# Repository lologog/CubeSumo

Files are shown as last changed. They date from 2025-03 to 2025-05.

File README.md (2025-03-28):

# CubeSumo - 🚧 Work in Progress
Minisumo robot built for sumo battles, equipped with multiple sensors for reliable navigation and opponent detection.

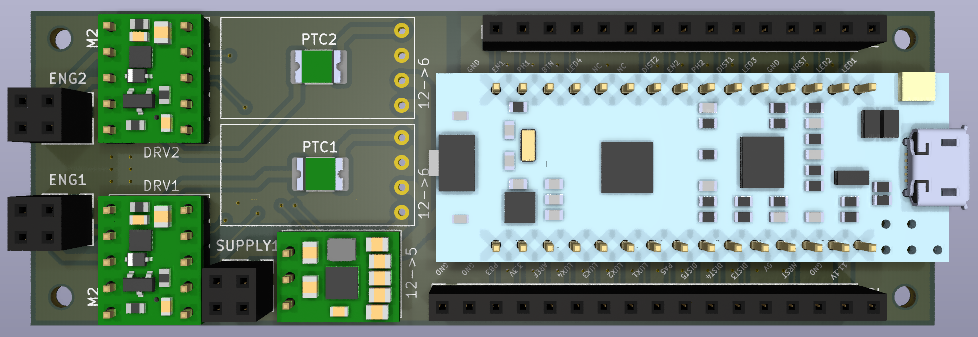
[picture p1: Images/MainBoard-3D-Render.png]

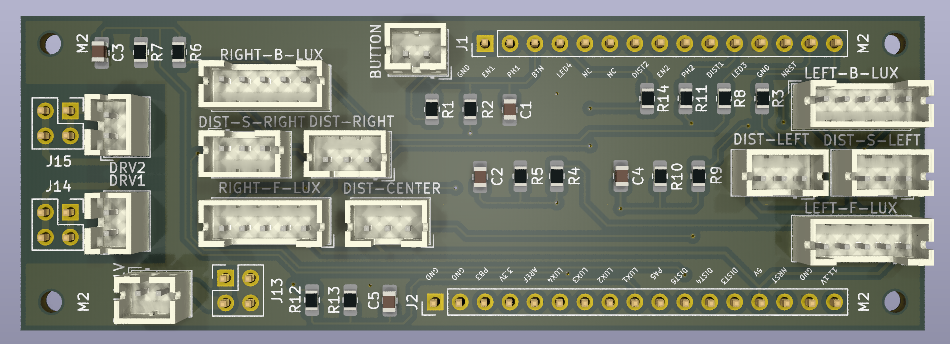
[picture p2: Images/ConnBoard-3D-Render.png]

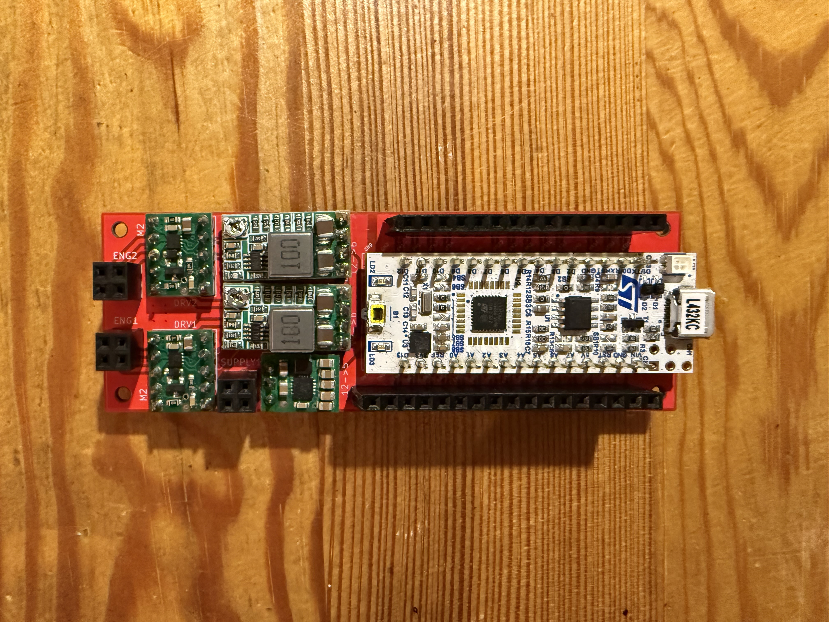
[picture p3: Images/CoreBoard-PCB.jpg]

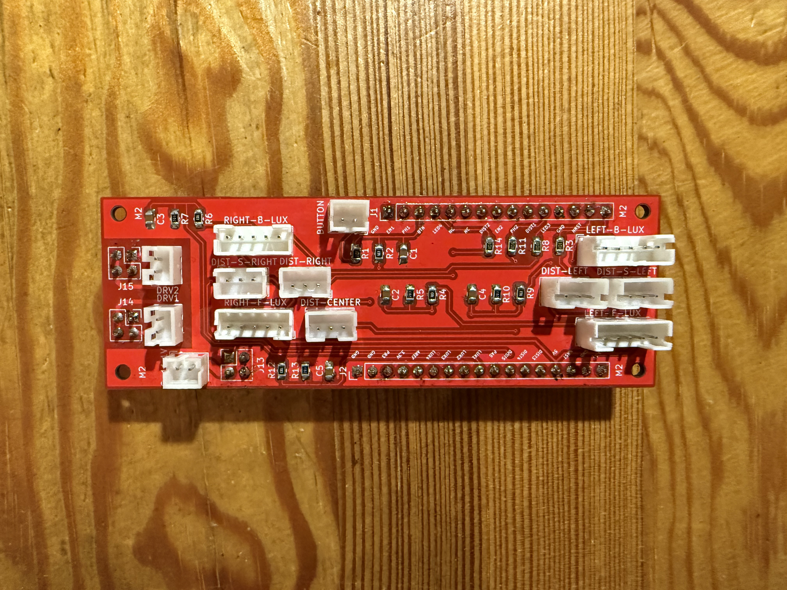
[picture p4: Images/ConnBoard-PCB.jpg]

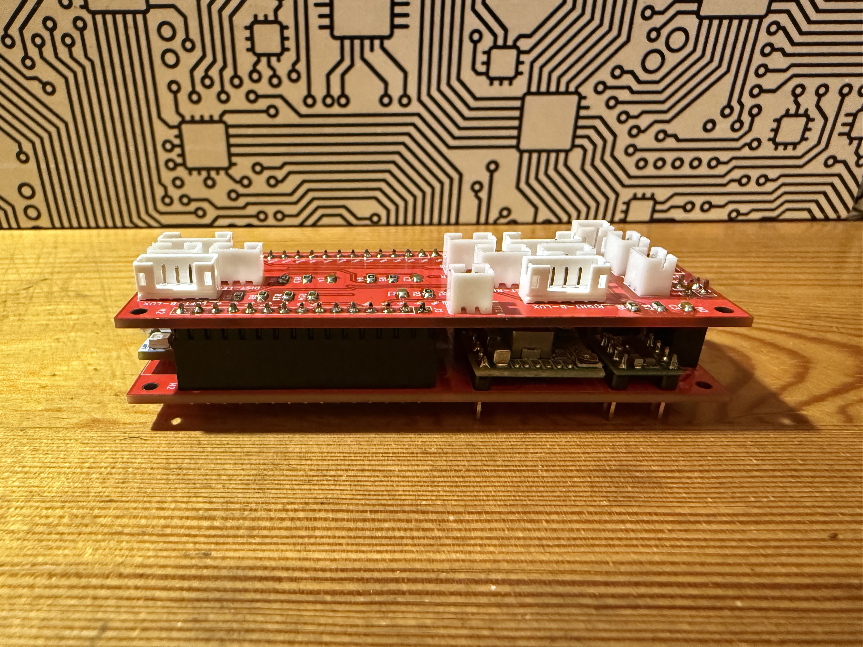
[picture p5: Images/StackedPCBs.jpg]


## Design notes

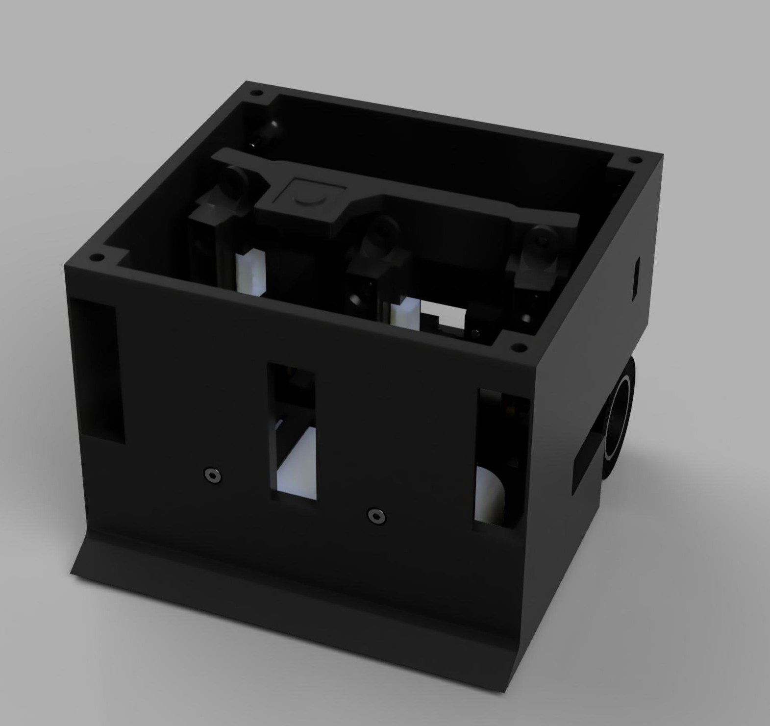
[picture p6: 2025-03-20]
Images/Zoeniowy_dziala_smaller.jpg

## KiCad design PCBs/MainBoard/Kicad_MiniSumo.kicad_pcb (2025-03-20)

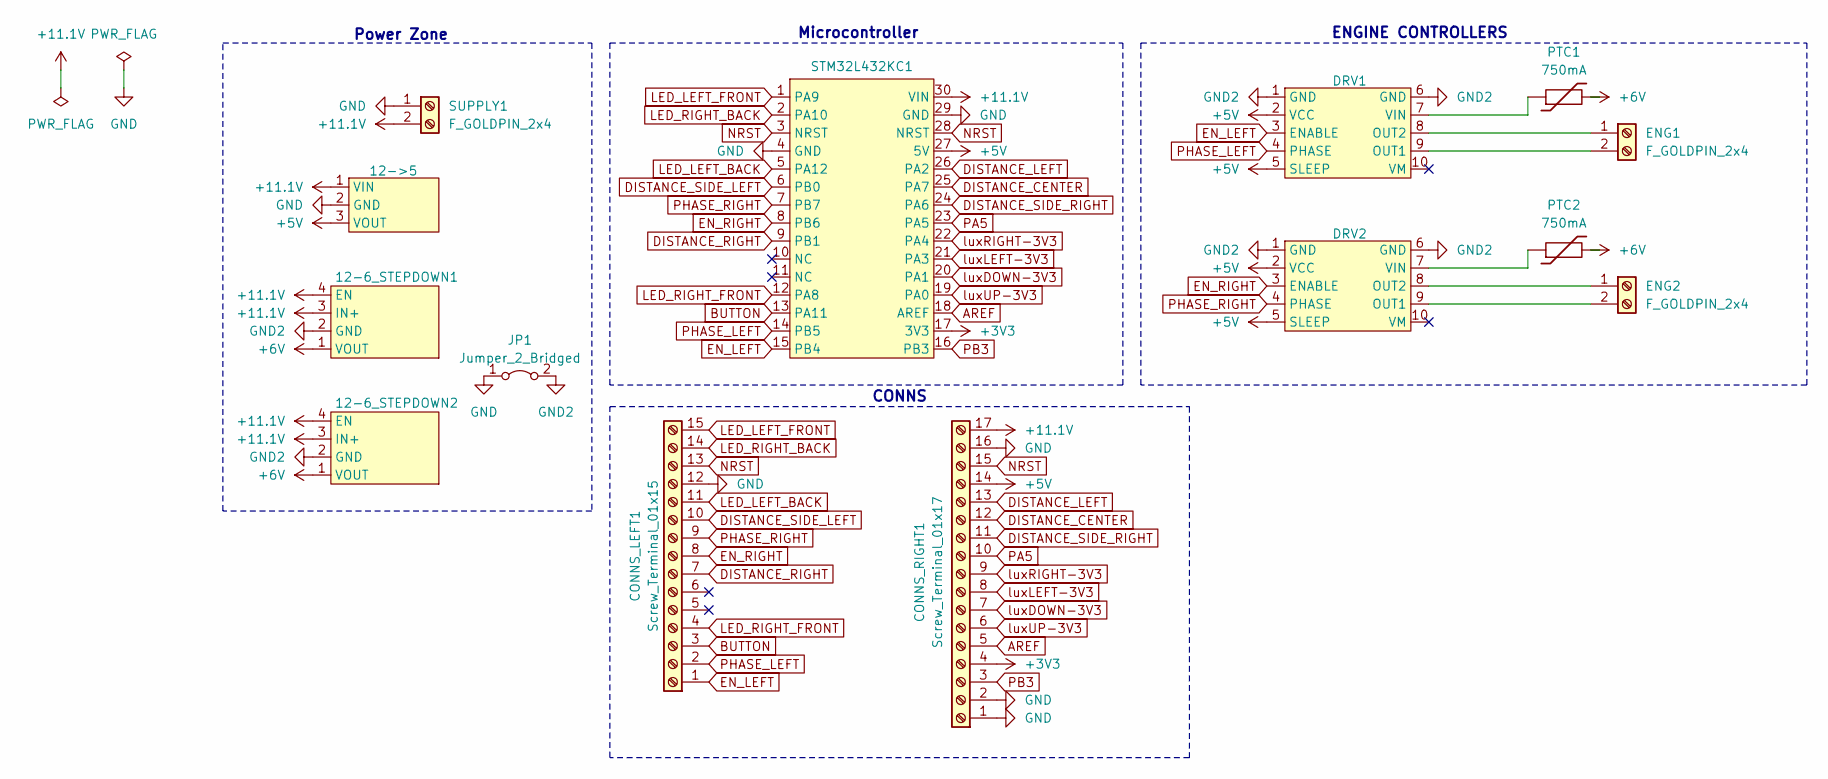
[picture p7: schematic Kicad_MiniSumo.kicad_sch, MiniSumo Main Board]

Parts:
12-6_STEPDOWN1, 12-6_STEPDOWN2: DC-DC Step-Down 0.8-17V 3A
12->5: S7V7F5
CONNS_LEFT1: Screw_Terminal_01x15; PinSocket_1x15_P2.54mm_Vertical
CONNS_RIGHT1: Screw_Terminal_01x17; PinSocket_1x17_P2.54mm_Vertical
DRV1, DRV2: DRV8838
ENG1, ENG2: F_GOLDPIN_2x4; PinSocket_2x02_P2.54mm_Vertical
JP1: Jumper_2_Bridged; SolderJumper-2_P1.3mm_Bridged2Bar_Pad1.0x1.5mm
PTC1, PTC2: 750mA; Fuse_1812_4532Metric_Pad1.30x3.40mm_HandSolder
STM32L432KC1: MODULE_NUCLEO-L432KC
SUPPLY1: F_GOLDPIN_2x4; PinSocket_2x02_P2.54mm_Vertical

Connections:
+3V3: CONNS_RIGHT1.4, STM32L432KC1.17 (3V3)
+5V: 12->5.3 (VOUT), CONNS_RIGHT1.14, DRV1.2 (VCC), DRV1.5 (SLEEP), DRV2.2 (VCC), DRV2.5 (SLEEP), STM32L432KC1.27 (5V)
+6V: 12-6_STEPDOWN1.1 (VOUT), 12-6_STEPDOWN2.1 (VOUT), PTC1.2, PTC2.2
+11.1V: 12-6_STEPDOWN1.3 (IN+), 12-6_STEPDOWN1.4 (EN), 12-6_STEPDOWN2.3 (IN+), 12-6_STEPDOWN2.4 (EN), 12->5.1 (VIN), CONNS_RIGHT1.17, STM32L432KC1.30 (VIN), SUPPLY1.2
AREF: CONNS_RIGHT1.5, STM32L432KC1.18 (AREF)
BUTTON: CONNS_LEFT1.3, STM32L432KC1.13 (PA11); also elsewhere on the board
DISTANCE_CENTER: CONNS_RIGHT1.12, STM32L432KC1.25 (PA7)
DISTANCE_LEFT: CONNS_RIGHT1.13, STM32L432KC1.26 (PA2)
DISTANCE_RIGHT: CONNS_LEFT1.7, STM32L432KC1.9 (PB1); also elsewhere on the board
DISTANCE_SIDE_LEFT: CONNS_LEFT1.10, STM32L432KC1.6 (PB0); also elsewhere on the board
DISTANCE_SIDE_RIGHT: CONNS_RIGHT1.11, STM32L432KC1.24 (PA6)
EN_LEFT: CONNS_LEFT1.1, DRV1.3 (ENABLE), STM32L432KC1.15 (PB4); also elsewhere on the board
EN_RIGHT: CONNS_LEFT1.8, DRV2.3 (ENABLE), STM32L432KC1.8 (PB6); also elsewhere on the board
GND: 12->5.2 (GND), CONNS_LEFT1.12, CONNS_RIGHT1.1, CONNS_RIGHT1.2, CONNS_RIGHT1.16, JP1.1 (A), STM32L432KC1.4 (GND), STM32L432KC1.29 (GND), SUPPLY1.1; also elsewhere on the board
GND2: 12-6_STEPDOWN1.2 (GND), 12-6_STEPDOWN2.2 (GND), DRV1.1 (GND), DRV1.6 (GND), DRV2.1 (GND), DRV2.6 (GND), JP1.2 (B)
LED_LEFT_BACK: CONNS_LEFT1.11, STM32L432KC1.5 (PA12); also elsewhere on the board
LED_LEFT_FRONT: CONNS_LEFT1.15, STM32L432KC1.1 (PA9); also elsewhere on the board
LED_RIGHT_BACK: CONNS_LEFT1.14, STM32L432KC1.2 (PA10); also elsewhere on the board
LED_RIGHT_FRONT: CONNS_LEFT1.4, STM32L432KC1.12 (PA8); also elsewhere on the board
NRST: CONNS_LEFT1.13, CONNS_RIGHT1.15, STM32L432KC1.3 (NRST), STM32L432KC1.28 (NRST); also elsewhere on the board
unnamed: DRV1.9 (OUT1), ENG1.2
unnamed: DRV1.8 (OUT2), ENG1.1
unnamed: DRV1.7 (VIN), PTC1.1
unnamed: DRV2.9 (OUT1), ENG2.2
unnamed: DRV2.8 (OUT2), ENG2.1
unnamed: DRV2.7 (VIN), PTC2.1
PA5: CONNS_RIGHT1.10, STM32L432KC1.23 (PA5)
PB3: CONNS_RIGHT1.3, STM32L432KC1.16 (PB3)
PHASE_LEFT: CONNS_LEFT1.2, DRV1.4 (PHASE), STM32L432KC1.14 (PB5); also elsewhere on the board
PHASE_RIGHT: CONNS_LEFT1.9, DRV2.4 (PHASE), STM32L432KC1.7 (PB7); also elsewhere on the board
luxDOWN-3V3: CONNS_RIGHT1.7, STM32L432KC1.20 (PA1)
luxLEFT-3V3: CONNS_RIGHT1.8, STM32L432KC1.21 (PA3)
luxRIGHT-3V3: CONNS_RIGHT1.9, STM32L432KC1.22 (PA4)
luxUP-3V3: CONNS_RIGHT1.6, STM32L432KC1.19 (PA0)

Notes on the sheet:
CONNS
Microcontroller
ENGINE CONTROLLERS
Power Zone

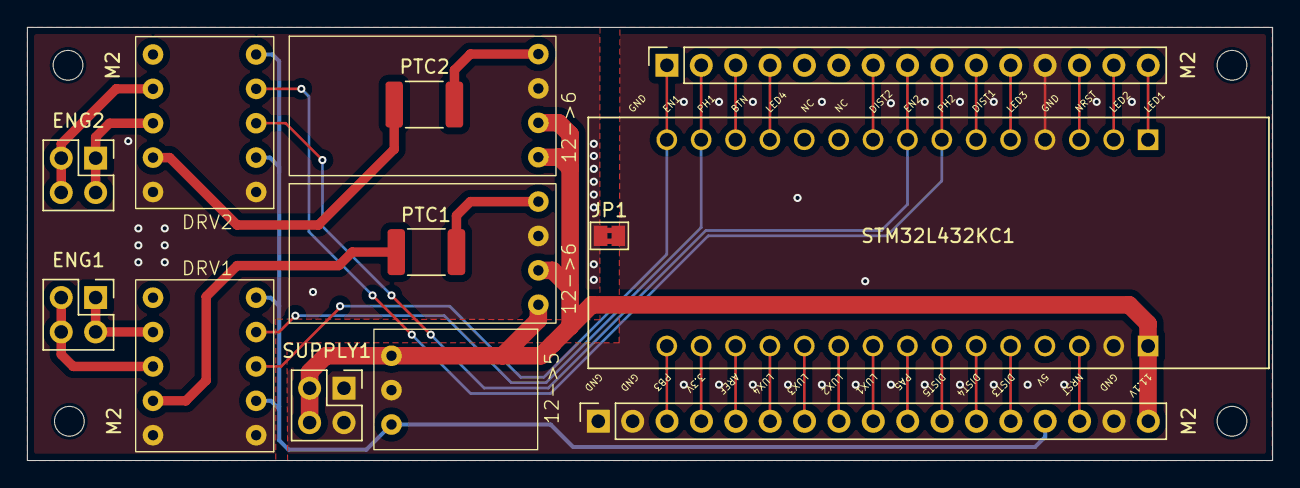
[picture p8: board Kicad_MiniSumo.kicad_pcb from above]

Board: 2 copper layers, 92.0 x 32.0 mm, 18 parts (0 on the bottom side), 34 nets.

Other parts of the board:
J1: Screw_Terminal_01x15; PinSocket_1x15_P2.54mm_Vertical
M2, M2#2, M2#3, M2#4: MountingHole_2.2mm_M2

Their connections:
BUTTON: J1.3; also elsewhere on the board
DISTANCE_RIGHT: J1.7; also elsewhere on the board
DISTANCE_SIDE_LEFT: J1.10; also elsewhere on the board
EN_LEFT: J1.1; also elsewhere on the board
EN_RIGHT: J1.8; also elsewhere on the board
GND: J1.12; also elsewhere on the board
LED_LEFT_BACK: J1.11; also elsewhere on the board
LED_LEFT_FRONT: J1.15; also elsewhere on the board
LED_RIGHT_BACK: J1.14; also elsewhere on the board
LED_RIGHT_FRONT: J1.4; also elsewhere on the board
NRST: J1.13; also elsewhere on the board
PHASE_LEFT: J1.2; also elsewhere on the board
PHASE_RIGHT: J1.9; also elsewhere on the board

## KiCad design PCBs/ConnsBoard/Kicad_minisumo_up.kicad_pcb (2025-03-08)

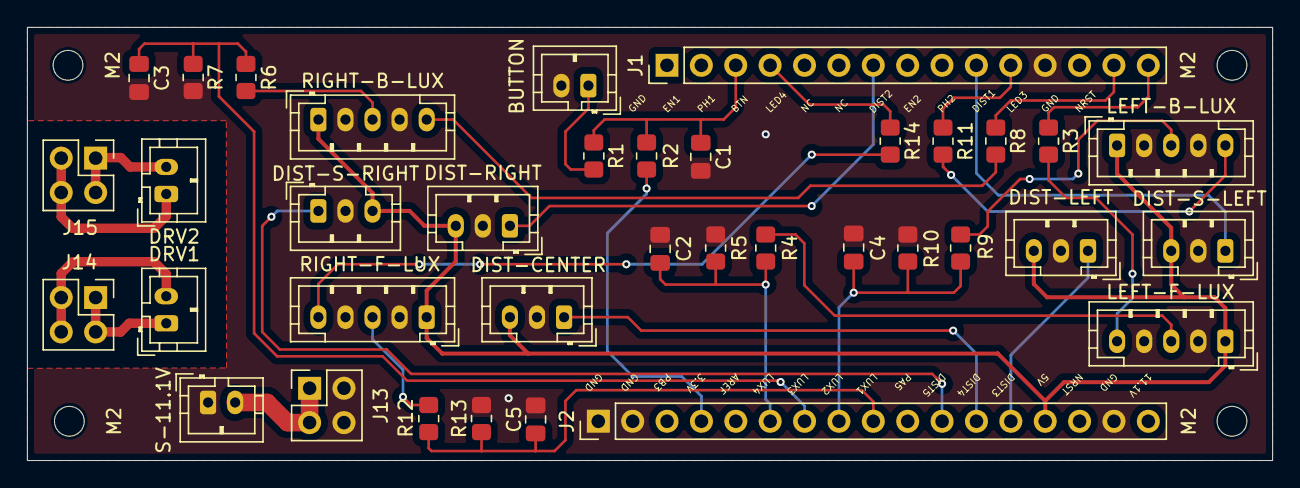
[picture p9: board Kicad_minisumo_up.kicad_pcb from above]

Board: 2 copper layers, 92.0 x 32.0 mm, 41 parts (0 on the bottom side), 32 nets.

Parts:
BUTTON: button; JST_PH_B2B-PH-K_1x02_P2.00mm_Vertical
C1: 100nF; C_0805_2012Metric_Pad1.18x1.45mm_HandSolder
C2, C3, C4, C5: 100NF; C_0805_2012Metric_Pad1.18x1.45mm_HandSolder
DIST-CENTER: distance center; JST_PH_B3B-PH-K_1x03_P2.00mm_Vertical
DIST-LEFT: distance_left; JST_PH_B3B-PH-K_1x03_P2.00mm_Vertical
DIST-RIGHT: distance_right; JST_PH_B3B-PH-K_1x03_P2.00mm_Vertical
DIST-S-LEFT: distance_side_left; JST_PH_B3B-PH-K_1x03_P2.00mm_Vertical
DIST-S-RIGHT: distance_side_right; JST_PH_B3B-PH-K_1x03_P2.00mm_Vertical
DRV1, DRV2: JST; JST_PH_B2B-PH-K_1x02_P2.00mm_Vertical
J1: Screw_Terminal_01x15; PinHeader_1x15_P2.54mm_Vertical
J2: Screw_Terminal_01x17; PinHeader_1x17_P2.54mm_Vertical
J13, J14, J15: screw; PinHeader_2x02_P2.54mm_Vertical
LEFT-B-LUX: lux_left_back; JST_PH_B5B-PH-K_1x05_P2.00mm_Vertical
LEFT-F-LUX: lux_left_front; JST_PH_B5B-PH-K_1x05_P2.00mm_Vertical
M2, M2#2, M2#3, M2#4: MountingHole_2.2mm_M2
R1: 1k; R_0805_2012Metric_Pad1.20x1.40mm_HandSolder
R2, R4, R6, R9, R12: 10k; R_0805_2012Metric_Pad1.20x1.40mm_HandSolder
R3, R8, R11, R14: 100; R_0805_2012Metric_Pad1.20x1.40mm_HandSolder
R5, R7, R10, R13: 20k; R_0805_2012Metric_Pad1.20x1.40mm_HandSolder
RIGHT-B-LUX: lux_right_back; JST_PH_B5B-PH-K_1x05_P2.00mm_Vertical
RIGHT-F-LUX: lux_right_front; JST_PH_B5B-PH-K_1x05_P2.00mm_Vertical
S-11.1V: JST; JST_PH_B2B-PH-K_1x02_P2.00mm_Vertical

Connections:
+3V3: J2.4, R2.1
+5V: DIST-CENTER.3, DIST-LEFT.3, DIST-RIGHT.3, DIST-S-LEFT.3, DIST-S-RIGHT.3, J2.14, LEFT-B-LUX.1, LEFT-F-LUX.1, RIGHT-B-LUX.1, RIGHT-F-LUX.1
+11.1V: J13.2, S-11.1V.2
BUTTON: C1.1, J1.3, R1.1, R2.2
DISTANCE_CENTER: DIST-CENTER.1, J2.12
DISTANCE_LEFT: DIST-LEFT.1, J2.13
DISTANCE_RIGHT: DIST-RIGHT.1, J1.7
DISTANCE_SIDE_LEFT: DIST-S-LEFT.1, J1.10
DISTANCE_SIDE_RIGHT: DIST-S-RIGHT.1, J2.11
DRV1_OUT1: DRV1.2, J14.2
DRV1_OUT2: DRV1.1, J14.1
DRV2_OUT1: DRV2.2, J15.2
DRV2_OUT2: DRV2.1, J15.1
GND: BUTTON.2, C1.2, C2.2, C3.2, C4.2, C5.2, DIST-CENTER.2, DIST-LEFT.2, DIST-RIGHT.2, DIST-S-LEFT.2, DIST-S-RIGHT.2, J1.12, J2.1, J2.2, J2.16, J13.1, LEFT-B-LUX.2, LEFT-B-LUX.4, LEFT-F-LUX.2, LEFT-F-LUX.4, R5.2, R7.2, R10.2, R13.2, RIGHT-B-LUX.2, RIGHT-B-LUX.4, RIGHT-F-LUX.2, RIGHT-F-LUX.4, S-11.1V.1
LED_LEFT_BACK: J1.11, R11.1
LED_LEFT_FRONT: J1.15, R3.1
LED_RIGHT_BACK: J1.14, R8.1
LED_RIGHT_FRONT: J1.4, R14.1
NRST: J1.13, J2.15
unnamed: BUTTON.1, R1.2
unnamed: LEFT-F-LUX.5, R3.2
unnamed: R8.2, RIGHT-B-LUX.5
unnamed: LEFT-B-LUX.5, R11.2
unnamed: R14.2, RIGHT-F-LUX.5
luxDOWN-3V3: C3.1, J2.7, R6.2, R7.1
luxDOWN-5V: R6.1, RIGHT-B-LUX.3
luxLEFT-3V3: C4.1, J2.8, R9.2, R10.1
luxLEFT-5V: LEFT-B-LUX.3, R9.1
luxRIGHT-3V3: C5.1, J2.9, R12.2, R13.1
luxRIGHT-5V: R12.1, RIGHT-F-LUX.3
luxUP-3V3: C2.1, J2.6, R4.2, R5.1
luxUP-5V: LEFT-F-LUX.3, R4.1

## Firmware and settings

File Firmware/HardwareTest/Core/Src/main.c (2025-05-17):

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
/* Includes ------------------------------------------------------------------*/
#include "main.h"

/* USER CODE BEGIN PD */
#define NUM_SENSORS (9) //how many analog sensors are used in the robot
#define SOFTWARE_PWM_PERIOD (5) //software PWM period in ticks - the less the fester is the PWM freq
#define DEBOUNCE_THRESHOLD (5) //number of stable reads required to confirm a new button state
/* USER CODE END PD */

ADC_HandleTypeDef hadc1;

void SystemClock_Config(void);
static void MX_GPIO_Init(void);
static void MX_ADC1_Init(void);
/* USER CODE BEGIN 0 */

//Enum for all states in state machine
typedef enum
{
    STATE_IDLE,
    STATE_WAIT_FOR_START,
    STATE_FIGHT
} RobotState_t;

//struct that associates an ADC channel with a pointer to its output variable
typedef struct
{
    uint32_t channel;
    uint32_t* value_ptr;
} Sensor_t;

//struct that stores info about button state
typedef struct
{
    uint8_t current;          //current debounced button state  <== use this for external usage
    uint8_t previous;         //previous debounced state
    uint8_t rising_edge;      //set to 1 for one loop cycle when a press is detected
    uint8_t falling_edge;     //set to 1 for one loop cycle when a release is detected
    uint8_t stable_state;     //internal filtered state
    uint8_t debounce_counter; //counter for debounce filtering
} ButtonState_t;

//enum representing current motor direction state
typedef enum {
    DIR_STOP,
    DIR_FORWARD,
    DIR_BACKWARD,
    DIR_LEFT,
    DIR_RIGHT
} Direction_t;

//variables used to store analog values read from sensors
uint32_t adc_value_1, adc_value_2, adc_value_3, adc_value_4;
uint32_t adc_value_5, adc_value_6, adc_value_7, adc_value_8, adc_value_9;

static uint8_t pwm_counter = 0; //PWM counter incremented every 1ms from SysTick

//variable tracking current movement direction
Direction_t current_direction = DIR_STOP;

//global variables storing duty cycle 0-100% for left and right motors
volatile uint8_t pwm_left = 0;
volatile uint8_t pwm_right = 0;

//button state
ButtonState_t button = {0};

//holder for current state in state machine
RobotState_t current_state = STATE_IDLE;

//array that maps ADC channels to their corresponding sensor value variables
Sensor_t sensors[NUM_SENSORS] =
{
    {ADC_CHANNEL_16, &adc_value_1},
    {ADC_CHANNEL_11, &adc_value_2},
    {ADC_CHANNEL_12, &adc_value_3},
    {ADC_CHANNEL_7,  &adc_value_4},
    {ADC_CHANNEL_15, &adc_value_5},
    {ADC_CHANNEL_9,  &adc_value_6},
    {ADC_CHANNEL_6,  &adc_value_7},
    {ADC_CHANNEL_5,  &adc_value_8},
    {ADC_CHANNEL_8,  &adc_value_9}
};

//selects the specified ADC channel and prepares it for conversion
void ADC_SetActiveChannel(ADC_HandleTypeDef *hadc, uint32_t AdcChannel)
{
  ADC_ChannelConfTypeDef sConfig = {0};
  sConfig.Channel = AdcChannel;
  sConfig.Rank = 1;
  sConfig.SamplingTime = ADC_SAMPLETIME_12CYCLES_5;
  if (HAL_ADC_ConfigChannel(hadc, &sConfig) != HAL_OK)
  {
	  Error_Handler();
  }
}

//reads values from all configured ADC channels and stores the results
void UpdateAllSensors(void)
{
    for (int i = 0; i < NUM_SENSORS; i++)
    {
        ADC_SetActiveChannel(&hadc1, sensors[i].channel);
        HAL_ADC_Start(&hadc1);

        if (HAL_ADC_PollForConversion(&hadc1, 10) == HAL_OK)
        {
        	//store the value directly in the variable pointed to by the sensor
            *(sensors[i].value_ptr) = HAL_ADC_GetValue(&hadc1);
        }
    }
}

//stops both motors by disabling the enable pins
void StopMotors(void)
{
    HAL_GPIO_WritePin(EN_LEFT_GPIO_Port, EN_LEFT_Pin, GPIO_PIN_RESET);
    HAL_GPIO_WritePin(EN_RIGHT_GPIO_Port, EN_RIGHT_Pin, GPIO_PIN_RESET);
    pwm_left = 0;
    pwm_right = 0;
    current_direction = DIR_STOP;
}

//stops motors briefly if direction is changing to avoid shoot-through
void SafeDirectionChange(Direction_t new_dir)
{
    if (current_direction != DIR_STOP && current_direction != new_dir)
    {
        StopMotors();
        HAL_Delay(100); //dead time to allow safe switching
    }
}

//moves robot forward at specified speed (0–100%)
void MoveBack(uint8_t speed_percent)
{
    SafeDirectionChange(DIR_FORWARD);

    HAL_GPIO_WritePin(PHASE_LEFT_GPIO_Port, PHASE_LEFT_Pin, GPIO_PIN_SET);
    HAL_GPIO_WritePin(PHASE_RIGHT_GPIO_Port, PHASE_RIGHT_Pin, GPIO_PIN_SET);

    uint8_t duty;

    if (speed_percent > 100)
    {
        duty = SOFTWARE_PWM_PERIOD;
    }
    else
    {
        duty = (speed_percent * SOFTWARE_PWM_PERIOD) / 100;
    }

    pwm_left = duty;
    pwm_right = duty;

    current_direction = DIR_FORWARD;
}

//moves robot backward at specified speed (0–100%)
void MoveForward(uint8_t speed_percent)
{
    SafeDirectionChange(DIR_BACKWARD);

    HAL_GPIO_WritePin(PHASE_LEFT_GPIO_Port, PHASE_LEFT_Pin, GPIO_PIN_RESET);
    HAL_GPIO_WritePin(PHASE_RIGHT_GPIO_Port, PHASE_RIGHT_Pin, GPIO_PIN_RESET);

    uint8_t duty;

    if (speed_percent > 100)
    {
        duty = SOFTWARE_PWM_PERIOD;
    }
    else
    {
        duty = (speed_percent * SOFTWARE_PWM_PERIOD) / 100;
    }

    pwm_left = duty;
    pwm_right = duty;

    current_direction = DIR_BACKWARD;
}

//spins robot left so it turns in place at specified speed
void TurnLeft(uint8_t speed_percent)
{
    SafeDirectionChange(DIR_LEFT);

    HAL_GPIO_WritePin(PHASE_LEFT_GPIO_Port, PHASE_LEFT_Pin, GPIO_PIN_RESET);
    HAL_GPIO_WritePin(PHASE_RIGHT_GPIO_Port, PHASE_RIGHT_Pin, GPIO_PIN_SET);

    uint8_t duty;

    if (speed_percent > 100)
    {
        duty = SOFTWARE_PWM_PERIOD;
    }
    else
    {
        duty = (speed_percent * SOFTWARE_PWM_PERIOD) / 100;
    }

    pwm_left = duty;
    pwm_right = duty;

    current_direction = DIR_LEFT;
}

//spins robot right so it turns in place at specified speed
void TurnRight(uint8_t speed_percent)
{
    SafeDirectionChange(DIR_RIGHT);

    HAL_GPIO_WritePin(PHASE_LEFT_GPIO_Port, PHASE_LEFT_Pin, GPIO_PIN_SET);
    HAL_GPIO_WritePin(PHASE_RIGHT_GPIO_Port, PHASE_RIGHT_Pin, GPIO_PIN_RESET);

    uint8_t duty;

    if (speed_percent > 100)
    {
        duty = SOFTWARE_PWM_PERIOD;
    }
    else
    {
        duty = (speed_percent * SOFTWARE_PWM_PERIOD) / 100;
    }

    pwm_left = duty;
    pwm_right = duty;

    current_direction = DIR_RIGHT;
}

//software based PWM controller - should be called every 1ms from SysTick_Handler :)
void SoftwarePWM_Loop(void)
{
    pwm_counter++;
    if (pwm_counter >= SOFTWARE_PWM_PERIOD)
    {
    	pwm_counter = 0;
    }


    //left motor PWM
    if (pwm_counter < pwm_left)
    {
    	HAL_GPIO_WritePin(EN_LEFT_GPIO_Port, EN_LEFT_Pin, GPIO_PIN_SET);
    }
    else
    {
    	HAL_GPIO_WritePin(EN_LEFT_GPIO_Port, EN_LEFT_Pin, GPIO_PIN_RESET);
    }

    //right motor PWM
    if (pwm_counter < pwm_right)
    {
    	HAL_GPIO_WritePin(EN_RIGHT_GPIO_Port, EN_RIGHT_Pin, GPIO_PIN_SET);
    }
    else
    {
    	HAL_GPIO_WritePin(EN_RIGHT_GPIO_Port, EN_RIGHT_Pin, GPIO_PIN_RESET);
    }
}

//turn LEDs under the robot on and off
void LEDsOnOff(uint8_t state)
{
	if (state == 0)
	{
		HAL_GPIO_WritePin(LED1_GPIO_Port, LED1_Pin, GPIO_PIN_RESET);
		HAL_GPIO_WritePin(LED2_GPIO_Port, LED2_Pin, GPIO_PIN_RESET);
		HAL_GPIO_WritePin(LED3_GPIO_Port, LED3_Pin, GPIO_PIN_RESET);
		HAL_GPIO_WritePin(LED4_GPIO_Port, LED4_Pin, GPIO_PIN_RESET);
	}
	else
	{
		HAL_GPIO_WritePin(LED1_GPIO_Port, LED1_Pin, GPIO_PIN_SET);
		HAL_GPIO_WritePin(LED2_GPIO_Port, LED2_Pin, GPIO_PIN_SET);
		HAL_GPIO_WritePin(LED3_GPIO_Port, LED3_Pin, GPIO_PIN_SET);
		HAL_GPIO_WritePin(LED4_GPIO_Port, LED4_Pin, GPIO_PIN_SET);
	}
}

//calculates the button state including filtering
void UpdateButtonState(void)
{
    //read raw button input
    uint8_t raw_state = (HAL_GPIO_ReadPin(BTN_GPIO_Port, BTN_Pin) == GPIO_PIN_RESET) ? 1 : 0;

    //check if the raw state differs from the last confirmed stable state
    if (raw_state != button.stable_state)
    {
        //count how many times this new state was seen consecutively
        button.debounce_counter++;

        //if new state was long enough then accept it
        if (button.debounce_counter >= DEBOUNCE_THRESHOLD)
        {
            button.previous = button.stable_state;
            button.stable_state = raw_state;

            //edge detection
            button.rising_edge  = (button.previous == 0 && button.stable_state == 1);
            button.falling_edge = (button.previous == 1 && button.stable_state == 0);
        }
    }
    else
    {
        //reset debounce counter if state is sure
        button.debounce_counter = 0;

        //reset edge flags
        button.rising_edge = 0;
        button.falling_edge = 0;
    }

    //save debounced state for external use
    button.current = button.stable_state;
}
/* USER CODE END 0 */

/**
  * @brief  The application entry point.
  * @retval int
  */
int main(void)
{

  /* MCU Configuration--------------------------------------------------------*/

  /* Reset of all peripherals, Initializes the Flash interface and the Systick. */
  HAL_Init();

  /* Configure the system clock */
  SystemClock_Config();

  /* Initialize all configured peripherals */
  MX_GPIO_Init();
  MX_ADC1_Init();
  /* USER CODE BEGIN 2 */
  HAL_ADC_Start(&hadc1);

  /* USER CODE END 2 */

  /* Infinite loop */
  /* USER CODE BEGIN WHILE */
  while (1)
  {
	  UpdateAllSensors();
	  UpdateButtonState();

	  //STATE MACHINE
	  switch (current_state)
	  {
	  case STATE_IDLE:
		  //here we put logic for one state
		  LEDsOnOff(0);
		  StopMotors();

		  //here we check conditions when we want to go to the next state
		  if (button.rising_edge)
		  {
			  current_state = STATE_WAIT_FOR_START;
		  }
		  break;
	  case STATE_WAIT_FOR_START:
		  //......logic........
		  LEDsOnOff(1);
		  //......conditions........
		  break;
	  }

  /* USER CODE END WHILE */

  /* USER CODE BEGIN 3 */
  }
  /* USER CODE END 3 */
}

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


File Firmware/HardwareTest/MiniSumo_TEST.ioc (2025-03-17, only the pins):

Mcu.UserName=STM32L432KCUx
PA0.GPIO_Label=LUX3
PA0.Signal=ADCx_IN5
PA1.GPIO_Label=LUX2
PA1.Signal=ADCx_IN6
PA10.GPIO_Label=LED2
PA10.Signal=GPIO_Output
PA11.GPIO_Label=BTN
PA11.Signal=GPIO_Input
PA12.GPIO_Label=LED4
PA12.Signal=GPIO_Output
PA2.Signal=ADCx_IN7
PA3.GPIO_Label=LUX4
PA3.Signal=ADCx_IN8
PA4.GPIO_Label=LUX1
PA4.Signal=ADCx_IN9
PA6.Signal=ADCx_IN11
PA7.Signal=ADCx_IN12
PA8.GPIO_Label=LED1
PA8.Signal=GPIO_Output
PA9.GPIO_Label=LED3
PA9.Signal=GPIO_Output
PB0.Signal=ADCx_IN15
PB1.Signal=ADCx_IN16
PB5.GPIO_Label=PHASE_LEFT
PB5.Signal=GPIO_Output
PB6.GPIO_Label=EN_RIGHT
PB6.Signal=GPIO_Output
PB7.GPIO_Label=PHASE_RIGHT
PB7.Signal=GPIO_Output

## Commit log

2025-03-05 project: add PCBs photos to Images folder
2025-03-05 README: add PCBs photos
2025-03-08 Project: Add Locking to the PCB and one photo of 3D render
    [Kicad_MiniSumo.kicad_pcb, Kicad_MiniSumo.kicad_sch]
2025-03-08 Project: add ConnsBoard PCB files
    [Kicad_minisumo_up.kicad_pcb, Kicad_minisumo_up.kicad_sch]
2025-03-08 Project: Add 3D render photo of connectors board
2025-03-08 Project: fixing position of goldpins on ConnsBoard
    [Kicad_minisumo_up.kicad_pcb]
2025-03-14 Added information on PCB to change pads to thermal releases in next version!
    [Kicad_MiniSumo.kicad_pcb]
2025-03-17 Project: add information about CN16 jumper to the PCB project
    [Kicad_MiniSumo.kicad_pcb]
2025-03-17 Project: add STM32 project created to test hardware
2025-03-20 Project: add new comment about THTs on the main PCB board
    [Kicad_MiniSumo.kicad_pcb]
2025-05-17 Project: create more logic function to read ADC sensor values
2025-05-17 PROJECT: add all basic motion function togeter with software PWM function used in SysTick_Handler
2025-05-17 PROJECT: add LEDs control function
2025-05-17 PROJECT: add whole button state detection functionality

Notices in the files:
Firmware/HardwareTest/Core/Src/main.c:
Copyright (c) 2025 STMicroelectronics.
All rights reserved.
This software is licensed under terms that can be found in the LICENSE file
